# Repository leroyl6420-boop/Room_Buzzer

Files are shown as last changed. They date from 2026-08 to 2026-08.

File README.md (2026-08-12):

# Room_Buzzer
A buzzer for my room! (Mostly so that my little brother will get off my back about playing). The Room Buzzer is an ESP-32 powered device that you can put outside your room's door for your annoying siblings to ring when they want in. There are two buttons, so that they have an option between a "are you there?" and a "GET OUT HERE RIGHT NOW!!!!". There is a passive buzzer on the device for a satisfying buzz, and there are two LEDs to confirm the button presses. Due to the ESP-32's wireless capabilities, you may link the Room Buzzer with your laptop/computer to access the alerts. I plan on making a receiver module in the future, so that you can get notified without being on your computer. But introductions aside, here is everything there is to know about the Room Buzzer!

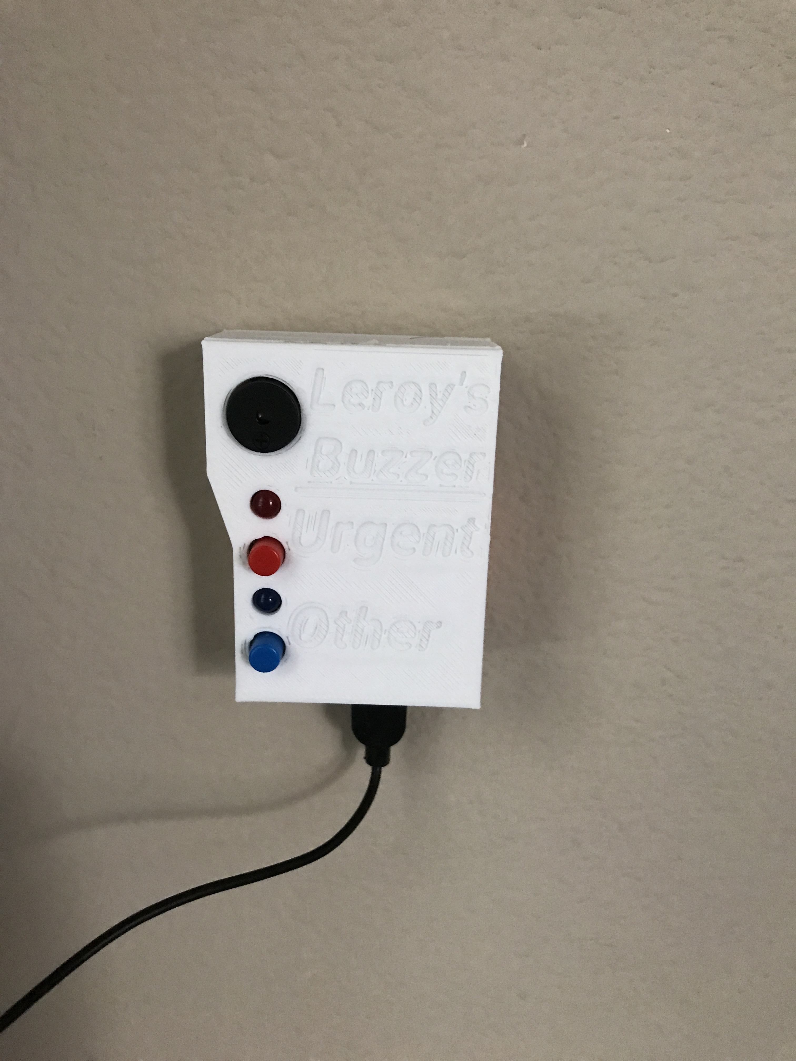
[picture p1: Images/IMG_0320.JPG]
A picture of the Room Buzzer V1.0


# Steps to Reproduce

If you're reading this, it either means that you want to build the Room Buzzer for yourself or you're the person reviewing my project! In that case, thank you very much for helping out in Hack Club, I'm a hardware reviewer myself (in Stardance) and I know that it's a pain when someone doesn't have all their stuff in order. Well, don't worry, I'm gonna do my job so you can do yours!

# BOM

The following is everything you will need to make the Room Buzzer:

- 6cm x 4cm perfboard: $0.30
- Passive Buzzer: $0.10
- Two 5mm LEDs (one blue, one red): $0.10
- Two Push Buttons (with caps, one blue, one red. They should be the two-pin variety): $0.10
- ESP32-WROOM: $2.50
- Elegoo Power MB V2: $2.00
- Power Micro-USB Cable: $2.00
- 9V Battery: $1.25
- 9V Battery Jack Cable: $0.15
- Two 220 ohm Resistors: $0.10
- 3D Printed Parts: NA
- Solder: NA
- 22/24 AWG Wire: NA

In total, the Room Buzzer will cost you around $8.60 before 3D printed parts, solder, wire, and taxes. All in all, pretty cheap!

# Assembly Instructoins

First, you'll want to get the perfboard all wired up. 

Side 1:

ESP-32 VIN: C14
ESP-32 D23: Q4

Side 2:

Passive Buzzer GND pin: A1
Passive Buzzer VCC pin: D1
Red LED GND pin: H1
Red LED VCC pin: I1
Red Button pin 1: K1
Red Button pin 2: M1
Blue LED VCC pin: O1
Blue LED GND pin: P1
Blue Button pin 1: R1
Blue Button pin 2: T1

GPIO Connections:

Red LED VCC: D25 (K14)  W/220 ohm RESISTOR
Blue LED VCC: D26 (L14)  W/220 ohm RESISTOR
Red Button (anypin): D32 (I14)
Blue Button (anypin): D33 (J14)
Passive Buzzer VCC: D27 (M14)

Of course, the unused legs of the buttons and the remaining pins shall go to either one of the ESP-32's GNDs. It should end up looking like this (on side 2):

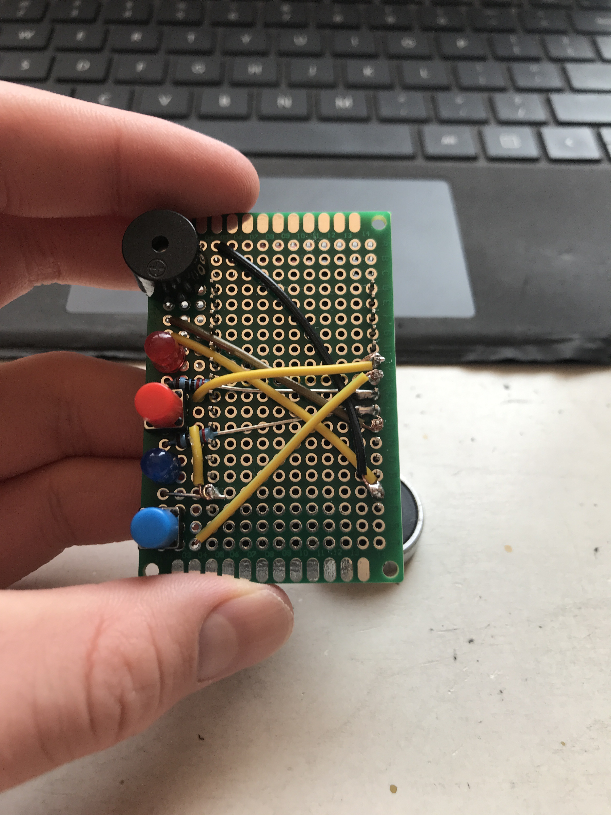
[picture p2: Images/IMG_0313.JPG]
An image of the Room Buzzer V1.0's perfboard


# Instructions on Use

To use the Room Buzzer after assembly, first use Arduino IDE to flash the Main.ino file onto your ESP-32. Then, assuming you're on windows (boo-hoo to you if you're not), open up Windows Powershell and copy/paste the Windows_PowerShell_CodeV1.0.txt file's contents into the terminal. Make sure to press "Enter". After the program prints "Room Buzzer is running..." and "Waiting for notifications...", you may have at it with the transmitter module. The alerts will be pop-ups on your laptop. Personally, I put my power module in my room, ran the Micro-USB cable through the crease of the door, and have my Room Buzzer sitting outside. It's fun!

# Image Gallery

The Room Buzzer V1.0:
![An image of the completed Room Buzzer V1.0}(Images/IMG_0320.JPG)

The casual alert button being pressed:
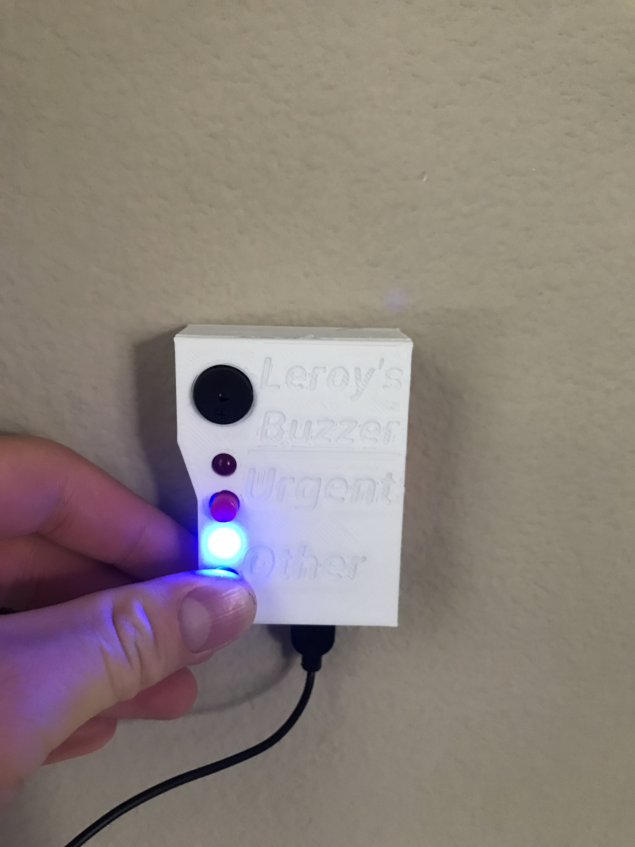
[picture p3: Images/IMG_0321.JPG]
An image of the Room Buzzer V1.0 as the casual button is being pressed


The urgent alert button being pressed:
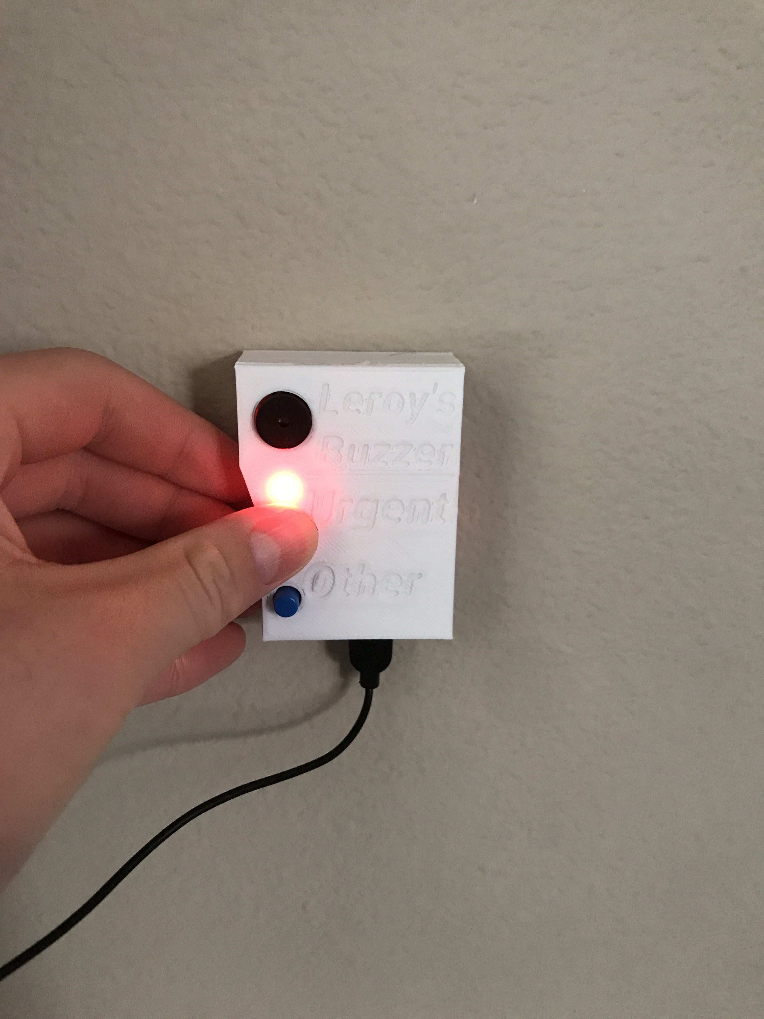
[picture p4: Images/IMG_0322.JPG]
An image of the Room Buzzer V1.0 as the urgent button is being pressed


The power module:
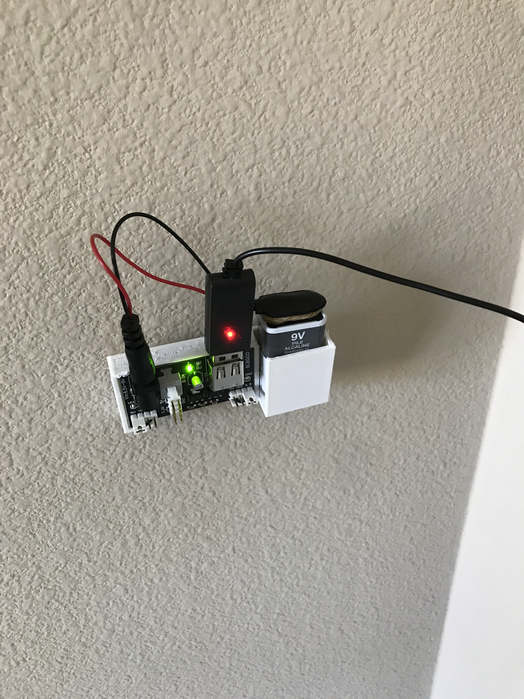
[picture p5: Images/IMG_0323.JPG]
An image of the Room Buzzer V1.0's power module


# AI Use

AI was used to code the Windows Powershell code. I didn't want to learn how to code in Windows Powershell just for this, so I used AI lol (:

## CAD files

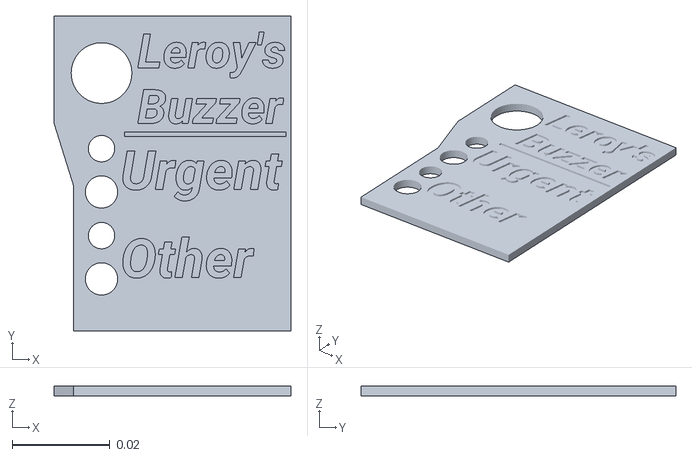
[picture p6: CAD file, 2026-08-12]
Parts to Print (STLs)/Cover.stl
0.0484 x 0.0644 x 0.002

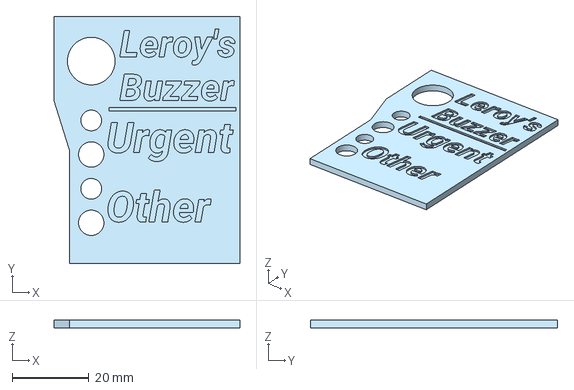
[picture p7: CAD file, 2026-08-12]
STEP Files/Cover.step
48.4 x 64.4 x 2.00 mm

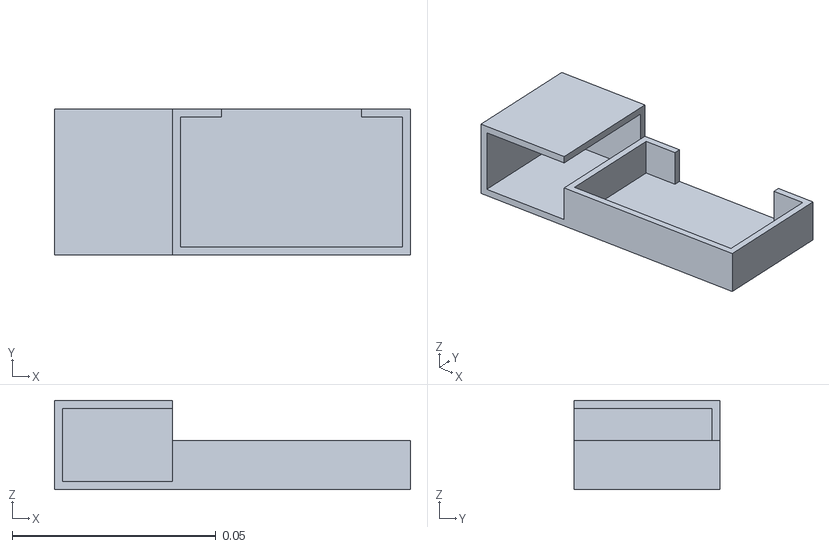
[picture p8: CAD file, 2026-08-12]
Parts to Print (STLs)/Power Module.stl
0.0873 x 0.0359 x 0.0219

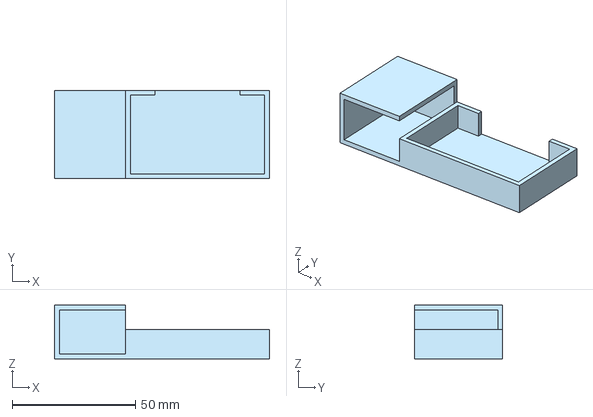
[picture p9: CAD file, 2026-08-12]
STEP Files/Power Module.step
87.3 x 35.9 x 21.9 mm

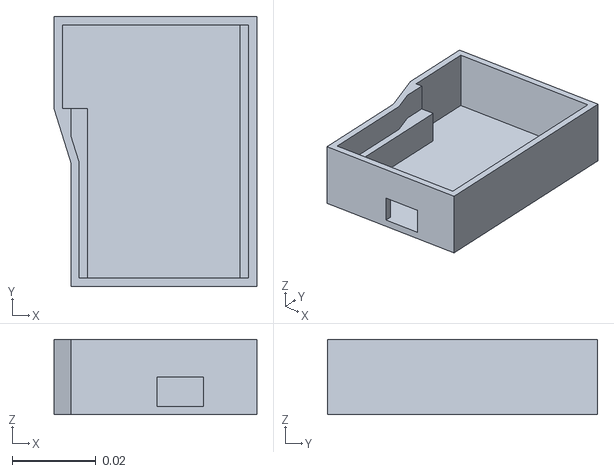
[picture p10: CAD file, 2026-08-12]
Parts to Print (STLs)/Bottom Case.stl
0.0484 x 0.0644 x 0.018

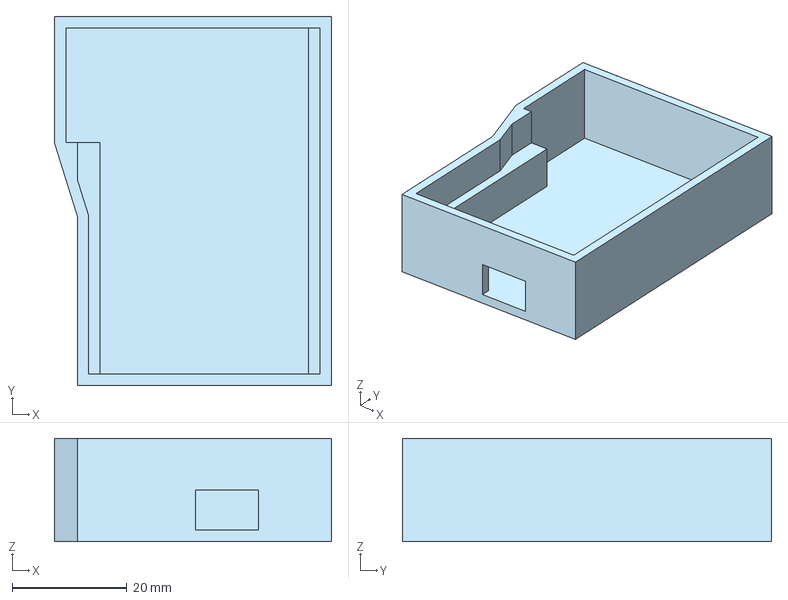
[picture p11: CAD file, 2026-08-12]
STEP Files/Bottom Case.step
48.4 x 64.4 x 18.0 mm

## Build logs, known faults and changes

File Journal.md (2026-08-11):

# Room Buzzer
Welcome to my hardware project, the Room Buzzer! This is the journal where I will be writing all my Devlogs, and where you can see how the project grew!

# Devlog 1
2h 0min 19sec Logged

I started the Room Buzzer today! I actually made really good progress in the very first CAD session. I would have paused in the middle to make two one-hour devlogs, but I was too locked in. I got the whole CAD done, and at the time that I am writing this devlog, the case and its face are being printed on my 3D printer! I didn't just CAD the printed parts, though. I also modeled the entire perfboard! Well, everything save the connections and the resistors. I found all their models online or in my library of common electronic parts' STEP files, and I fiddled around with their placement on a 6cm x 4cm perfboard until I got something I liked. I then modeled the entire case around it, just for the Micro USB to be too high on the side! I had to flip the ESP-32 onto the opposite side of the perfboard from everything else and practically start the case from scratch. Still, I'm happy with the end result. I'll be soldering the perfboard together tomorrow, and it'll be my first time doing that, so I'm very excited!

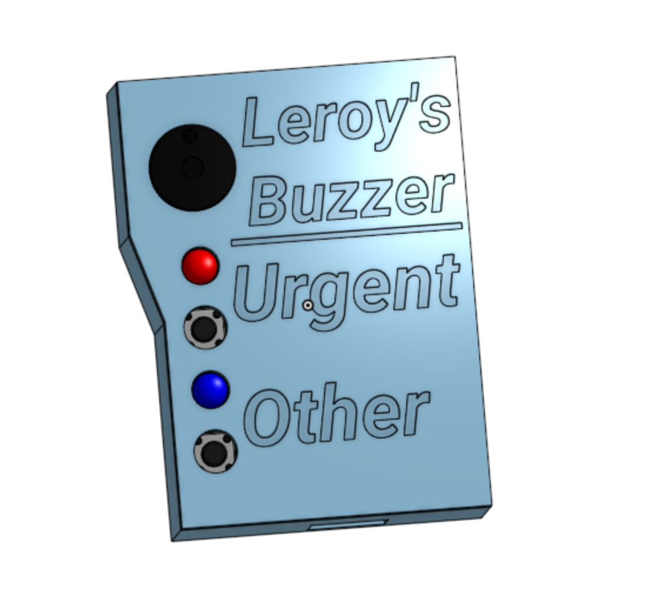
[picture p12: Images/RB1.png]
A picture of the completed CAD of the Room Buzzer

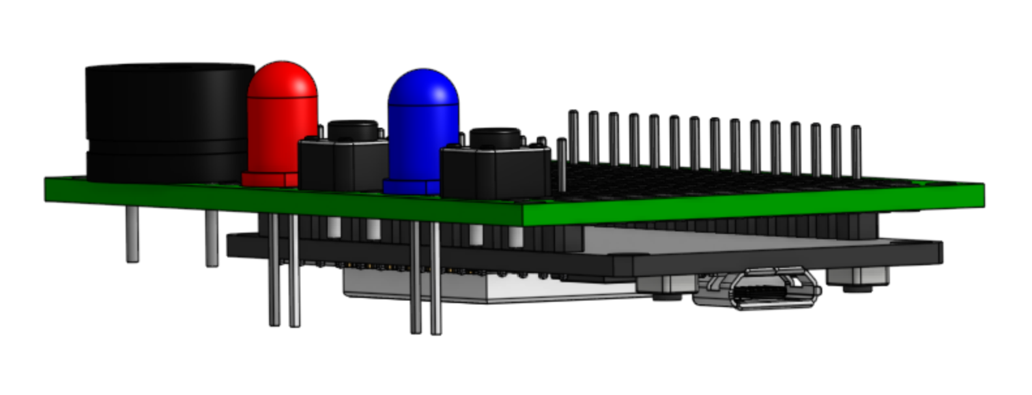
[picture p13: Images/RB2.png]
An image of the CADed perfboard of the Room Buzzer


# Devlog 2
1h 28min 0sec Logged

I started building the Room Buzzer today. I successfully soldered the whole perfboard together. It was the first time that I had done that, and it was really fun! It was pretty successful, too. I haven't tested it yet, but all the connections seem solid. Trouble came when I tried putting the perfboard into the case. Not only was the case poorly printed, the Micro USB port's hole was off as well. The cover was not much better, with the buzzer's hole being too low and the buttons' holes being too small. I'll have to fix all that now...

An image of the components side of the perfboard
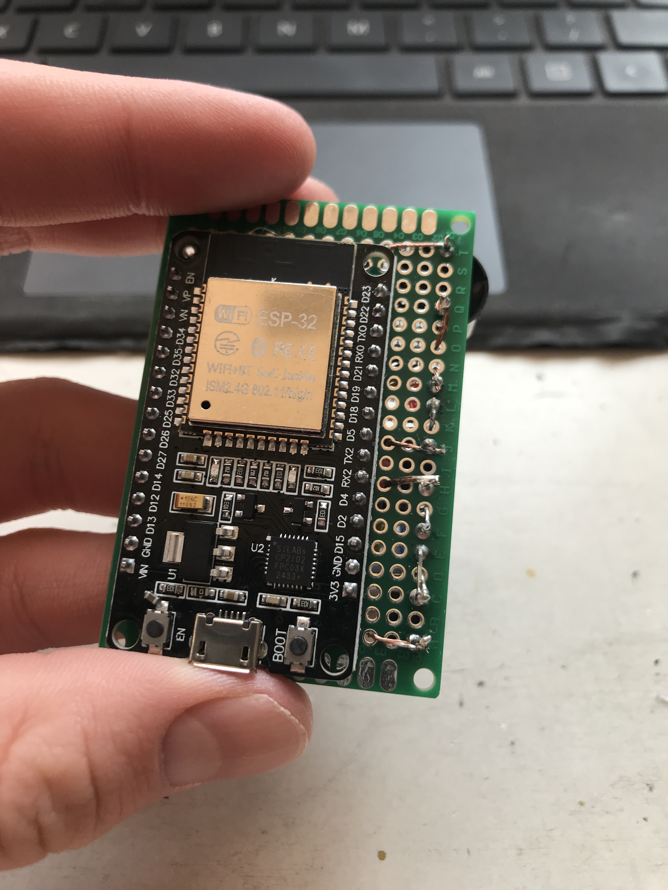
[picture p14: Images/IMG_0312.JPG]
An image of the ESP-32 side of the perfboard


# Devlog 3
1h 14min 9sec Logged

I finished the transmitter module of the Room Buzzer! I printed a new case and cover, and they both fit properly this time. I slapped a 9V battery-to-USB converter on the back, and it worked well. I even took a few pictures! Still, I want to use a different power source, which I'll be CADing a case for soon. The firmware was easier than I expected, as the button pressing, LED flashing, and buzzer buzzing were all the same as I had done before. What was different was using my home WiFi and Windows Powershell on my laptop to get notifications from the transmitter. Still, I want to be able to run this system without my laptop, and even without WiFi, so I'll be making a receiver module next, and updating the firmware to use ESP-NOW, which will be able to run locally. 

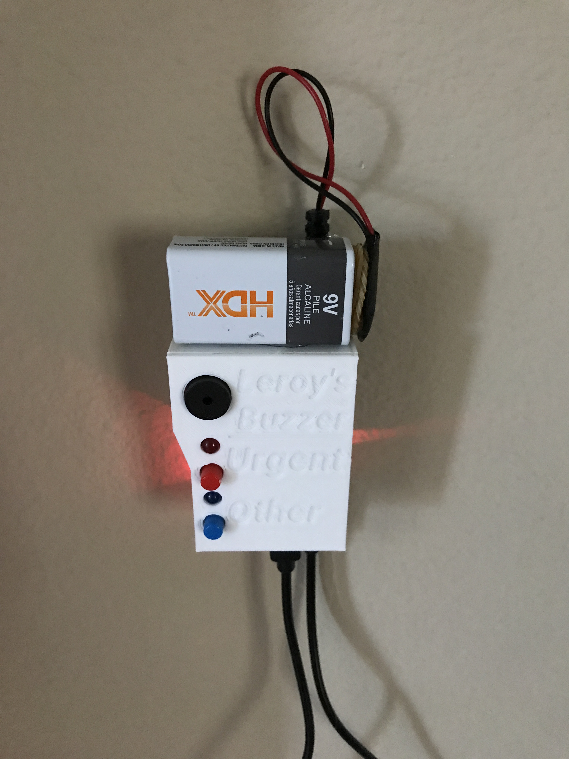
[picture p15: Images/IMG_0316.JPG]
An image of the set up Room Buzzer, V1.0

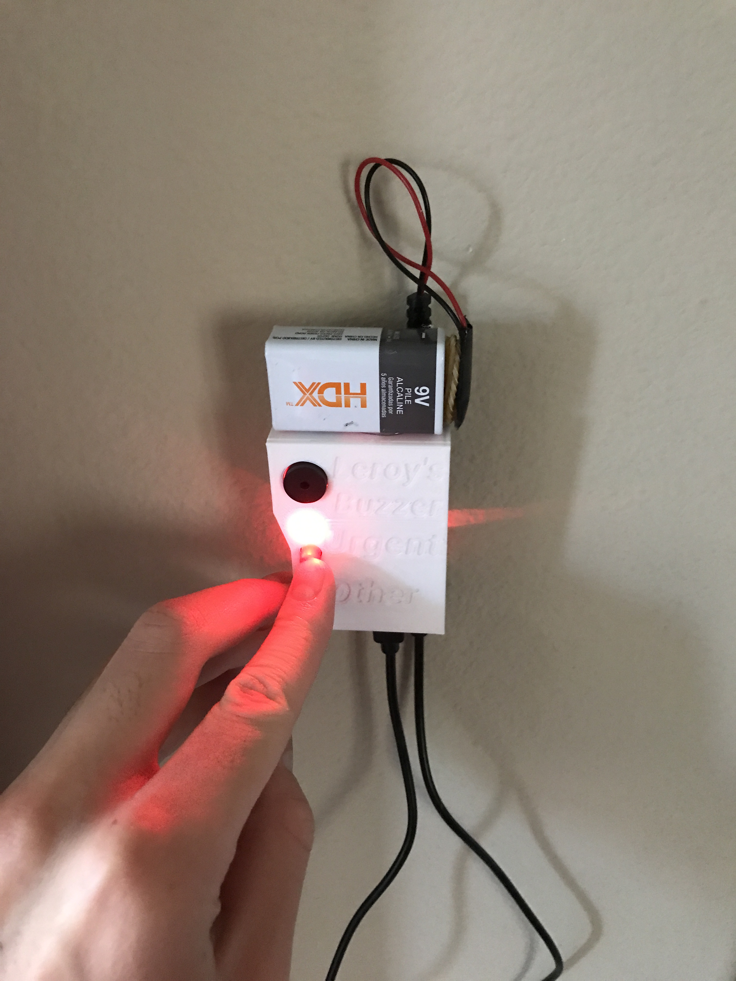
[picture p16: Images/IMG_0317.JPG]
An image of the Room Buzzer with the Urgent button being pressed

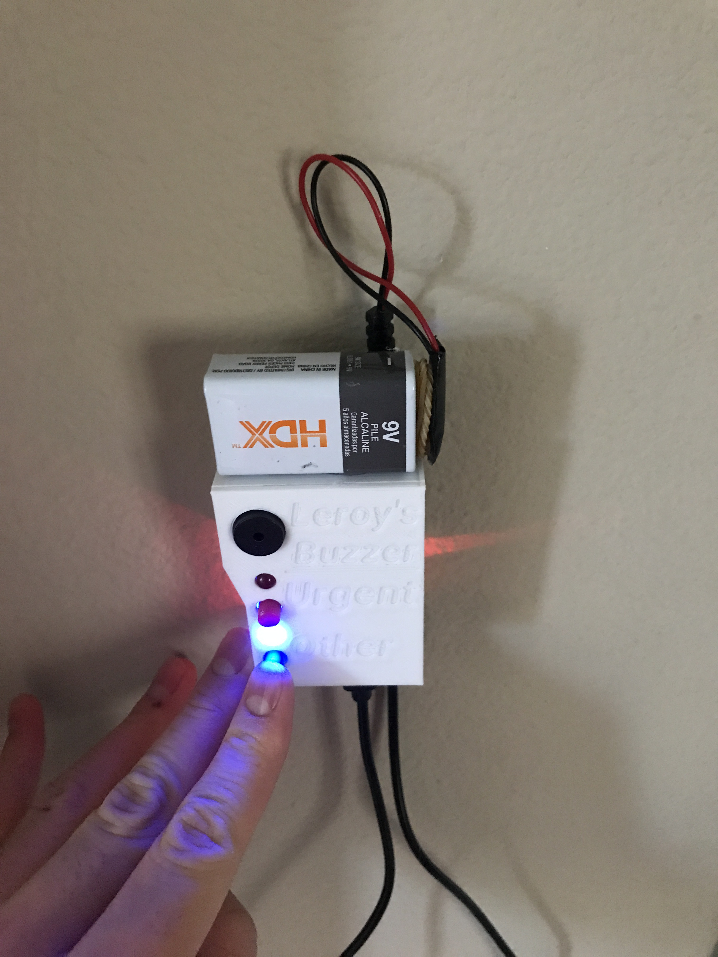
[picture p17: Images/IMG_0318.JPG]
An image of the Room Buzzer with the Casual button being pressed


# Devlog 4
1h 27min 0sec Logged

I CADed both the power module and the receiver module. I decided to avoid using a perfboard in my receiver module, as I only have one left and I want to be able to reuse this ESP-32 in the future. That meant that this receiver module has to be a lot larger than the transmitter module. Still, it should work alright. The power module was simple: an Elegoo Power MB V2 holster and a 9V battery holster in one. I'll set it up inside my room, run the wire through the crack in the door, and have the buzzer be outside my door. 

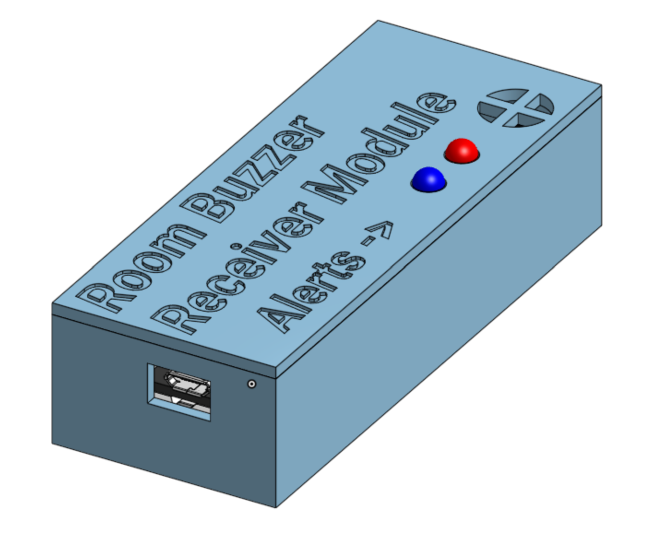
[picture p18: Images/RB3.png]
A picture of the receiver module

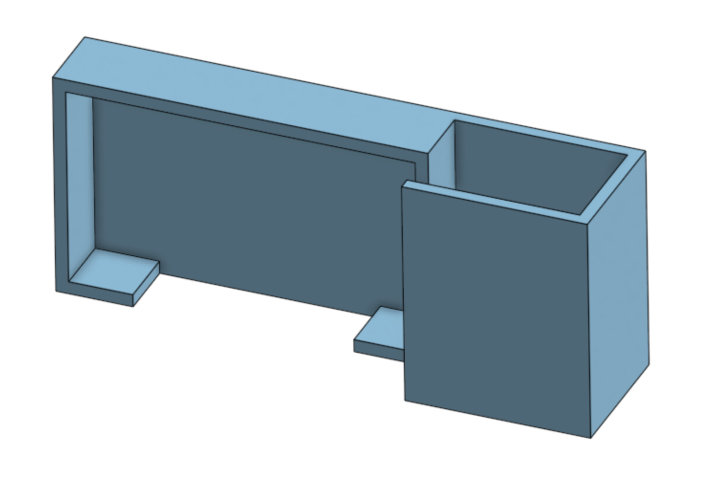
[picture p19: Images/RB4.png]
A picture of the power module


# Devlog 5
1h 13min 0sec Logged

I CADed a model of the Elegoo Power MB V2 for my Power Module assembly. I will do the same for the resistors and wires on the perfboard next. Though I wanted to make a receiver module, it seems that I will no longer be able to, as my 3D printer's extruder broke this morning. The replacement will not arrive in time for the Horizons program. I will be forced to content myself with laptop notifications. 

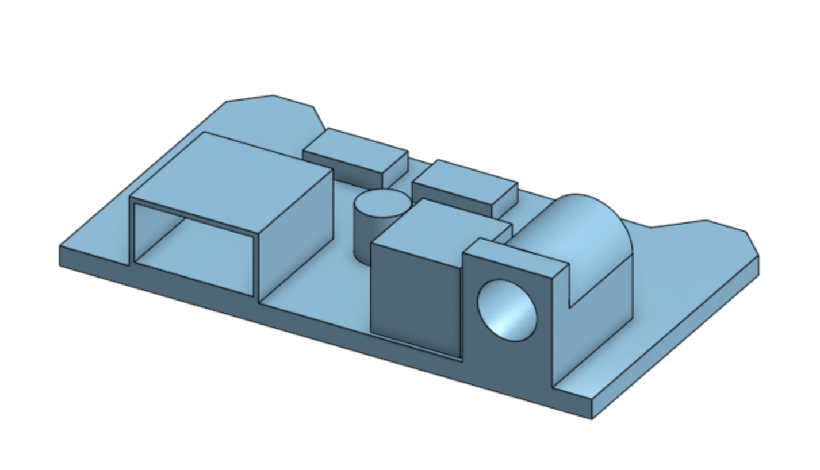
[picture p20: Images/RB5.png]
An image of the new Power Module assembly


# Devlog 6
1h 30min 0sec Logged

I started CADing all the wire connections on the perfboard. It was sorta my first time using the Revolve tool on OnShape, which is kinda embarrassing to admit, and it took me a while to figure out, but the wires' turns turned out alright. I finished pretty much everything on the underside of the board, and now I'll model all the connections up on top of the board. I hope that this will help anyone wanting to make a Room Buzzer for themselves wire the perfboard correctly. 

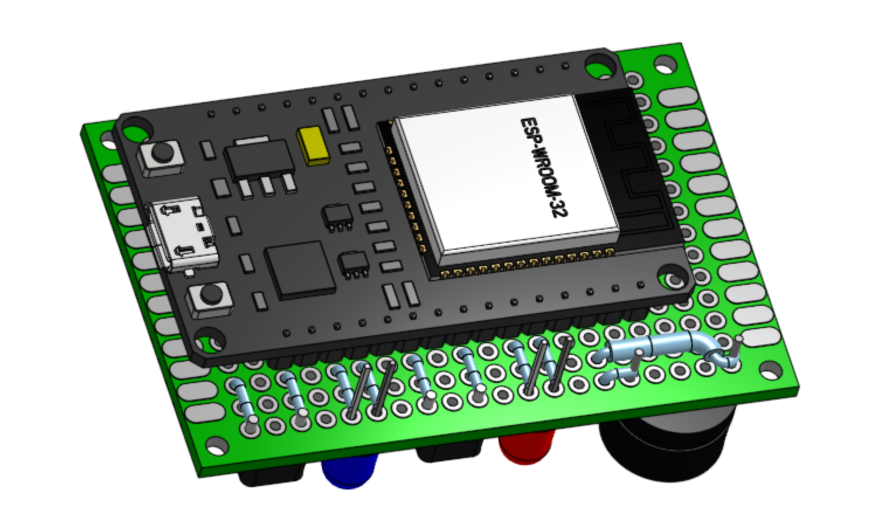
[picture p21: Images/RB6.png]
An image of the underside of the perfboard CAD, with the wires now modeled


# Devlog 7
1h 31min 0sec Logged

I finished CADing the wires in the perfboard assembly! Again, since my 3D printer is broken, this is the last contribution I will be making to the Room Buzzer, at least for the time being. I'll wrap things up in my README so that you can make the Room Buzzer too! I hope you find the assembly useful in wiring (:

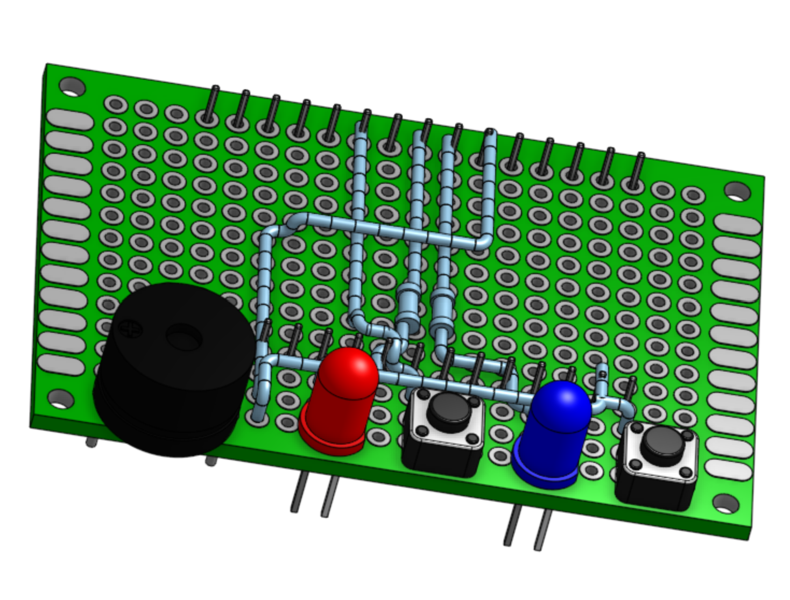
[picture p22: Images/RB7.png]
An image of the finished perfboard CAD


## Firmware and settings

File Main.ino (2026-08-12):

// Hi! Welcome to the Room Buzzer code! Really, it's gonna be super
// simple, but I'm doing this mostly for the heartbeat. 

#include <WiFi.h>
#include <NetworkUdp.h>
NetworkUDP udp;
const char* laptopIP = "192.168.1.250";
const int laptopPort = 4210;
const char* wifiName = "Delepres";
const char* wifiPassword = "99993568";
#define RED_LED 25
#define BLUE_LED 26
#define RED_BUTTON 32
#define BLUE_BUTTON 33
#define BUZZER 27
bool BlueButtonPressed = false;
bool RedButtonPressed = false;
bool LastBlueButton = false;
bool LastRedButton = false;
unsigned long NotificationCooldown = 0;

void sendMessage(const char* message) {
    udp.beginPacket(laptopIP, laptopPort);
    udp.print(message);
    udp.endPacket();
    Serial.print("Sent: ");
    Serial.println(message);
}

void setup() {
    Serial.begin(115200);
    Serial.println("Connecting to Wifi");
    WiFi.begin(wifiName, wifiPassword);
    while (WiFi.status() != WL_CONNECTED) {
        delay(500);
        Serial.print(".");
    }
    Serial.println();
    Serial.println("Connected!");
    Serial.print("ESP32 IP adress:");
    Serial.println(WiFi.localIP());
    udp.begin(4211);
    pinMode(RED_LED, OUTPUT);
    pinMode(BLUE_LED, OUTPUT);
    pinMode(BUZZER, OUTPUT);
    pinMode(RED_BUTTON, INPUT_PULLUP);
    pinMode(BLUE_BUTTON, INPUT_PULLUP);
}

void loop() {
    digitalWrite(RED_LED, LOW);
    digitalWrite(BLUE_LED, LOW);
    noTone(BUZZER);
    BlueButtonPressed = false;
    RedButtonPressed = false;
    if (digitalRead(BLUE_BUTTON) == LOW) {
        digitalWrite(BLUE_LED, HIGH);
        BlueButtonPressed = true;
    }
    if (digitalRead(RED_BUTTON) == LOW) {
        digitalWrite(RED_LED, HIGH);
        tone(BUZZER, 3000);
        RedButtonPressed = true;
    }
    if (BlueButtonPressed == true && LastBlueButton == false && millis() > NotificationCooldown){
        sendMessage("Casual Notification from Room Buzzer");
        NotificationCooldown = millis() + 1000;
    }
    if (RedButtonPressed == true && LastRedButton == false && millis() > NotificationCooldown){
        sendMessage("Urgent Notification from Room Buzzer");
        NotificationCooldown = millis() + 1000;
    }
    LastBlueButton = BlueButtonPressed;
    LastRedButton = RedButtonPressed;
}

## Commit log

2026-08-12 Rename Cover (1).step to Cover.step
    [Cover.step]
2026-08-12 Rename Bottom Case (2).stl to Bottom Case.stl
    [Bottom Case.stl]
2026-08-12 Rename Cover (2).stl to Cover.stl
    [Cover.stl]
2026-08-12 Rename Power Module (2).stl to Power Module.stl
    [Power Module.stl]
